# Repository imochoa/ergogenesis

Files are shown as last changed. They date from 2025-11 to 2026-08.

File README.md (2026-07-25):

https://www.youtube.com/watch?v=X0gTMRLRNp0

# Refs
- https://docs.ergogen.xyz/
- [measure your hand](https://pashutk.com/ergopad/)
    - https://github.com/pashutk/ergopad

- flatfootfox but for my usecase:   I'd take a look at the Sweep-like example on https://ergogen.ceoloide.com/ (via the dropdown). It does the sort of direct-pin + GND setup you're looking for;

- Check out my Corney Island (https://github.com/ceoloide/corney-island), it's a 100% replica of the Corne but has support for other switches (I use Lofree switches and I am loving it)

# Similar boards
https://github.com/auryn31/avocado
https://github.com/Narkoleptika/josukey

## [Part 1: Units](https://flatfootfox.com/ergogen-part1-units-points/)
Play around on https://ergogen.ceoloide.com/

## [Part 2: Outlines](https://flatfootfox.com/ergogen-part2-outlines/)
- https://github.com/scipioni/clavis

## [Part 3: PCB](https://flatfootfox.com/ergogen-part3-pcbs/)

## [Part 4: ](https://flatfootfox.com/ergogen-part4-footprints-cases/)

https://github.com/freerouting/freerouting

# ferris reversible examples
https://github.com/davidphilipbarr/Sweep/tree/main/Sweep%20half-swept

# Routing
1. Generate `outputs/pcbs/*.kicad_pcb
2. start kicad (`pcbnew`)
    1. import `.kicad_pcb`
    2. save it to let KiCAD auto-convert the file to the newer kicad sytanx
3. `File > Export > Specctra DSN` to generate a `.dsn` file
    - save at `ergogenesis/hardware/ergogen/output/pcbs/shield-pcb.dsn`
4. Start [freerouting](https://github.com/freerouting/freerouting)
    1. run it
6. save output as a Specctra SESSION in GUI `-routed.ses`
7. from kicad, with `.kicad_pcb` from before still open...
    1. `File > Import > Specctra Session`

# 3D models

Component STEP models live in `hardware/ergogen/3dmodels/` and are wired into the
footprints in `hardware/ergogen/config.yaml` via each footprint's `*_3dmodel_filename`
params. The generated `output/pcbs/shield-pcb.kicad_pcb` references them with
the `${ERGOGEN_3DMODELS}` KiCad path variable.

Models (downloaded from github.com/Andreyod1/Axiom, the ScottoKeebs library):
- `choc_v1.step` — Kailh Choc V1 switch (PG1353)
- `choc_hotswap.step` — Choc hotswap socket
- `choc_keycap_1u.step` — MBK 1u keycap
- `supermini_nrf52840.step` — Nice!Nano V2 STEP as a SuperMini NRF52840
  stand-in (same Pro Micro form factor / USB-C; no public SuperMini STEP
  exists)
- `switch_msk12c02.step` — MSK12C02 / SSSS811101 side slide switch
- `jst_ph_s2b.step` — JST PH 2.0 side-entry battery connector (S2B-PH-K,
  from the KiCad standard library)

To make KiCad's 3D viewer resolve them, add the path variable once:
- KiCad -> Preferences -> Configure Paths... -> Add
  - Name:  `ERGOGEN_3DMODELS`
  - Value:  `<repo>/hardware/ergogen/3dmodels`

Then open `hardware/ergogen/output/pcbs/shield-pcb.kicad_pcb` -> View -> 3D Viewer.

# Cases & plates

The `cases:` section generates a sandwich case: the PCB sits between a
**stabilization (switch) plate** on top and a **base plate** on the bottom,
held together by M2 screws through the mounting holes.

- `switch_plate` / `switch_plate_ol.dxf` — top plate with Choc cutouts
  (13.8x13.8mm) at each key. The switch snaps into this plate so it can't
  fall out of the hotswap socket. 1.6mm thick (Choc clip engagement).
- `bottom_plate` / `bottom_plate_ol.dxf` — base plate with a clearance slot
  per key for the hotswap socket.

The DXFs (`output/outlines/`) are for laser/waterjet cutting the plates; the
`.jscad` cases (`output/cases/`) are 3D-printable extrusions. Convert jscad to
STL with:
```
just ergogen-stl-from-jscad
# or per file:
npx @jscad/cli@1 output/cases/switch_plate.jscad -of stla -o switch_plate.stl
```
Preview a plate outline:
```
just visualize-dxf ./output/outlines/switch_plate_ol.dxf
```

## Hotswap socket clearance (reversible board)

The Choc hotswap socket bridges the switch's central hole and a side hole on
the north side of each key. On this reversible footprint the socket sits
bottom-west when populated on the front and bottom-east when populated on the
back. Rather than generate two mirrored bases, the base uses one symmetric
12x5mm slot per key that covers **both** positions, so a single base works
for either side (and for both halves of a split where one PCB is flipped).

The slot size/position is controlled by `socket_cutout_w`, `socket_cutout_h`,
and `socket_cutout_y` in the `units:` section. If a socket fouls the base,
widening `socket_cutout_w` or raising `socket_cutout_y` gives more room.

## Notes / known gotchas

- The top-left mounting screw (`mountscrew_top_left`) sits ~2mm from the
  `pinky_top` key, so in the switch plate its hole merges into that key's
  Choc cutout. Move that screw (or the key) if you need a clean separate
  screw hole in the top plate. The base plate is unaffected.
- The case here is a bare sandwich (no walls). Walls can be added later by
  extruding an expanded outline and subtracting the board outline, à la the
  flatfootfox Part 4 case tutorial.

# ZMK
```
warning: Deprecated symbol NRF_STORE_REBOOT_TYPE_GPREGRET is enabled.
```

# Save container history

```
   0 drwxr-xr-x. 1 root   root    20 Jun  5  2024 ../
4.0K -rw-------. 1 ubuntu ubuntu 437 Nov 17 16:43 .bash_history
4.0K -rw-r--r--. 1 ubuntu ubuntu 220 Mar 31  2024 .bash_logout
4.0K -rw-r--r--. 1 root   root   475 Oct  4 14:44 .bashrc
   0 drwxr-xr-x. 5 ubuntu ubuntu  51 Nov 17 16:39 .cache/
   0 drwxr-xr-x. 3 ubuntu ubuntu  22 Nov 17 16:39 .cmake/
   0 drwxr-xr-x. 3 ubuntu ubuntu  20 Nov 17 16:30 .dotnet/
4.0K -rw-r--r--. 1 ubuntu ubuntu 760 Nov 17 16:39 .gitconfig
   0 drwx------. 2 ubuntu ubuntu  80 Nov 17 16:30 .gnupg/
   0 drwxr-xr-x. 1 root   root    17 Nov 17 15:32 .local/
4.0K -rw-r--r--. 1 ubuntu ubuntu 807 Mar 31  2024 .profile
   0 drwxr-xr-x. 2 ubuntu ubuntu  25 Nov 17 16:30 .ssh/
   0 drwxr-xr-x. 1 ubuntu ubuntu  70 Nov 17 16:30 .vscode-server/
   0 drwxr-xr-x. 1 ubuntu ubuntu   6 Nov 17 15:32 project/
```

# Reference

- https://github.com/ceoloide/corney-island
  - build in docker? https://github.com/ceoloide/corney-island/blob/main/build.sh
https://github.com/ceoloide/ergogen-footprints/tree/main

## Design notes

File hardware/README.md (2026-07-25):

# Learnings
## V1.0
- Only need to hw swap the pins that cannot be mapped via software

## V2.0
- the hotswap socket pads are long and connected to the plated holes! This makes heating them up for soldering quite hard

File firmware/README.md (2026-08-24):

 The new global-quick-tap-ms = <75>; settings makes it so that if any key was pressed within 75ms before the combo hit, the combo won't be run and instead the keys will register as taps.

This significantly reduces accidental activations during typing and made combos finally usable for me.

## Battery sensing and Pro Micro pin 21

Do not configure the SuperMini battery sensor on AIN7 / P0.31. The `nice_nano`
board maps that GPIO to Pro Micro pin 21, and this keyboard already uses pin 21
as a direct key input:

- left half: `middle_home` (`D` on the base layer)
- right half: `inner_top` (`Y` on the base layer)

A `zmk,battery-voltage-divider` node using `io-channels = <&adc 7>` takes over
P0.31 and stops both keys from scanning. Battery ADC sensing and split battery
proxying therefore stay disabled in `config/ergogenesis.conf` and
`config/boards/shields/ergogenesis/Kconfig.defconfig`. Re-route those keys or
use a different battery-sense GPIO before enabling battery measurement.

## Keymap Drawing

https://github.com/infused-kim/zmk-config/blob/chocofi/main/keymap_img/keymap_img_adjuster.py

```
echo 'Parsing ZMK keymap...'
keymap -c keymap_config.yaml parse -c 12 -z ../config/corne.keymap > keymap.yaml

# echo '\n\nAdjusting keymap yaml...'
# ./keymap_img_adjuster.py keymap.yaml

echo '\n\nDrawing keymap...'
keymap -c keymap_config.yaml draw --qmk-keyboard crkbd/rev1 --qmk-layout LAYOUT_split_3x6_3 keymap.yaml -s Base Nav Num Func Sym Adjust > keymap.svg
```

## External modules (urob)

Two [urob](https://github.com/urob) ZMK modules are pinned in
[`config/west.yml`](config/west.yml). Both track ZMK `main` (their `main`
branch) — the `v0.3` in their READMEs is a "match your ZMK release" convention,
not a floor — so they build against this repo's ZMK-main pin. Bump the SHAs in
`west.yml` to move forward, then re-run `just firmware west-update` + a pristine
build.

- **[zmk-unicode](https://github.com/urob/zmk-unicode)** — Unicode input via the
  `&uc` behavior. Type code points directly (`&uc 0xE4 0xC4` → `ä`/`Ä`) or with
  language macros (`&uc UC_DE_AE`). Supports six input systems (macOS, Linux,
  Linux-alt, WinCompose, Windows-Alt, Emacs) with **runtime switching** — the
  keymap sets a boot default via `UC_DEFAULT` / `default-mode` and the
  `&uc UC_SET_MACOS` / `&uc UC_SET_LINUX` keys on the `LY_CTL` layer flip it
  live (no host-OS auto-detection exists in ZMK; this is the switch). macOS
  needs the "Unicode Hex Input" keyboard enabled.

- **[zmk-helpers](https://github.com/urob/zmk-helpers)** — convenience macros for
  terser keymaps: `ZMK_COMBO`, `ZMK_MACRO`, `ZMK_HOLD_TAP`, `ZMK_MOD_MORPH`,
  `ZMK_LAYER`, and standardized key-position labels (`LT0`…`RH2`, `KEYS_L`,
  `KEYS_R`, `THUMBS`). Included via `#include "zmk-helpers/helper.h"`. The custom
  shield keeps a local snapshot of the module's standard `36.h` position labels
  so it remains self-contained. The module's `unicode-chars/*.dtsi` are
  deprecated in favor of the zmk-unicode module above.

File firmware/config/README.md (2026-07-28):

Overrides the sources at config/boards/shields/ergogenesis/ergogenesis.keymap

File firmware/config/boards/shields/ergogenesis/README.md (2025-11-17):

https://github.com/zmkfirmware/zmk/blob/main/app/boards/shields/cradio/README.md

# [https://zmk.dev/docs/development/hardware-integration/new-shield?keyboard-type=split#kscan](Kscan)

> **ZMK uses the blue color coded "Arduino" pin names to generate devicetree node references.**
For example, to refer to the pin labeled 0 in the diagram, use &pro_micro 0 in the devicetree files.

# Mapping pin numbers...
https://github.com/zmkfirmware/zmk/blob/4ec69cb7e658590adf6354027aca789b364a70c5/app/boards/arm/nrfmicro/arduino_pro_micro_pins.dtsi

`.dtsi` names are NOT the pin numbers!

https://github.com/zmkfirmware/zmk/blob/main/app/boards/shields/cradio/cradio.dtsi

https://github.com/zmkfirmware/zmk/tree/4ec69cb7e658590adf6354027aca789b364a70c5/app/boards/arm/nice_nano

https://github.com/zmkfirmware/zmk/blob/4ec69cb7e658590adf6354027aca789b364a70c5/app/boards/arm/nice_nano/arduino_pro_micro_pins.dtsi

PIN#? | ???? | D
-- | -- | --
0  | 8  | D0
1  | 6  | D1
2  | 17 | D2
3  | 20 | D3
4  | 22 | D4/A6
5  | 24 | D5
6  | 0  | D6/A7
7  | 11 | D7
8  | 4  | D8/A8
9  | 6  | D9/A9
10 | 9  | D10/A10
16 | 10 | D16
14 | 11 | D14
15 | 13 | D15
18 | 15 | D18/A0
19 | 2  | D19/A1
20 | 29 | D20/A2
21 | 31 | D21/A3

## Changing the pin numbers
https://github.com/zmkfirmware/zmk/tree/main/app/boards/shields/cradio#pin-arrangement

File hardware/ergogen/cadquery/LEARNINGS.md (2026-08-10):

# CadQuery path — learnings and notes

This document records what we learned while adding a CadQuery-based pipeline to
generate STEP/STL for the plates and full case directly from Ergogen DXFs, and
then verifying geometry parity against the existing JSCAD meshes.

## Why CadQuery

- FreeCAD CLI is capable but finicky for headless scripting (argument passing,
  module pathing, exporter behavior). We had trouble invoking our scripts
  reliably via `freecadcmd -c` and getting writes to land.
- CadQuery exposes a clean Python API on top of OCP/OpenCascade and runs as a
  normal Python process. With uv single-file scripts we get reproducible,
  dependency-isolated CLIs that are easy to call from `just`.

## Source geometry (DXFs)

All solids are built exclusively from outlines exported by Ergogen:

- switch_plate_ol.dxf — PCB outline minus Choc cutouts and screw holes
- bottom_plate_ol.dxf — PCB outline minus socket slots and screw holes
- case_base_ol.dxf — solid base (board outline minus screw holes)
- wall_ring_ol.dxf — outer perimeter ring (expanded outline minus board outline)
- standoff_ol.dxf — circles at screw positions (standoffs)
- holes_ol.dxf — screw through-holes
- switch_wall_cutout_ol.dxf — rectangle through the case wall for power switch
- usb_wall_cutout_ol.dxf — rectangle through the north wall for USB-C

Note: a few of these outlines were added to `config.yaml` specifically to make a
reliable case reconstruction possible in external CAD.

## Scripts (uv single-file CLIs)

- cadquery/extrude_dxf.py
  - Input: one DXF outline
  - Builds faces from closed wires, extrudes to a prism; if multiple wires are
    present, it treats the largest as the outer boundary and the rest as holes.
  - Output: STEP (+ optional STL)
  - Usage example:
    - uv run cadquery/extrude_dxf.py \
      --dxf ergogen/output/outlines/switch_plate_ol.dxf \
      --height 1.6 \
      --out-step ergogen/output/cases/switch_plate_cq.step \
      --out-stl ergogen/output/cases/switch_plate_cq.stl

- cadquery/build_case.py
  - Inputs: the DXF set listed above (via a directory), plus bottom/standoff
    heights and wall height.
  - Build recipe (all via boolean ops):
    - base = case_base_ol.extrude(bottom_th)
    - walls = wall_ring_ol.extrude(bottom_th + standoff_h + wall_h)
    - standoffs = standoff_ol.extrude(bottom_th + standoff_h)
    - case = base ∪ walls ∪ standoffs
    - holes = holes_ol.extrude(full_height) → case = case − holes
    - switch_cut, usb_cut extruded to full height → subtract from case
  - Output: STEP (+ optional STL)
  - Usage example:
    - uv run cadquery/build_case.py \
      --dxf-dir ergogen/output/outlines \
      --bottom-th 2.0 --standoff-h 2.0 --wall-h 5.0 \
      --out-step ergogen/output/cases/case_cq.step \
      --out-stl ergogen/output/cases/case_cq.stl

## Just recipes

- just hardware cq-build-plates — build switch/bottom plates (STEP+STL)
- just hardware cq-build-case — build the case (STEP+STL)
- just hardware cq-compare — compare CadQuery vs JSCAD meshes
- just hardware cq-iterate — one-shot build-everything-then-compare

These search heights from `ergogen/config.yaml` with ripgrep and write to
`ergogen/output/cases/`.

## Comparison methodology

- Tool: `ergogen/freecad/compare_meshes.py` (uv script using trimesh + scipy + rtree)
- Metrics:
  - Volume difference (absolute and relative %)
  - Surface area difference (absolute)
  - Approximate bidirectional Hausdorff distance (sampling-based)
- Defaults: ≤0.1% volume difference and ≤0.05 mm Hausdorff distance qualify as
  a match. You can pass different tolerances on the CLI if needed.

## Results (with current config)

- Switch plate: ΔV ~0.0033%, Hausdorff ~0.0071 mm (MATCH)
- Bottom plate: ΔV ~0.0024%, Hausdorff ~0.0075 mm (MATCH)
- Case (base+walls+standoffs−holes−cutouts): ΔV ~0.0025%, Hausdorff ~0.0142 mm (MATCH)

These are well within manufacturing tolerances and typical mesh discretization
error.

## API gotchas and fixes

- CadQuery DXF import returns a Workplane, not a Compound. Use:
  - `wp = importers.importDXF(path)`
  - `wires = [w for w in wp.wires().vals() if isinstance(w, cq.Wire) and w.Closed()]`
- Building solids from faces:
  - `cq.Face.makeFromWires(outer, holes)` creates a planar face with holes.
  - Faces don’t have `.extrude()`, so wrap in a Workplane: `cq.Workplane("XY").add(face).extrude(h)`
- Full case needs proper “holes in faces” handling (outer wire + hole wires).
  A naïve “extrude all wires, then subtract” can fail on shared boundaries.
- Export tolerances: CadQuery’s default tessellation was sufficient to match the
  JSCAD meshes within ~0.01 mm; if a future model needs tighter control, we can
  expose tessellation parameters explicitly.

## FreeCAD notes (why we pivoted)

- Argument passing through `freecadcmd` is inconsistent across versions. `--`
  and `--pass` behave differently; reading args and writing files was unreliable
  in our environment.
- Module import path for neighbor modules required extra `sys.path` tweaks.
- We left the FreeCAD scripts in place for reference, but the CadQuery path is
  now the recommended one.

## Dependencies

- uv is used to run the single-file scripts. Install once from Astral if
  missing.
- CadQuery pulls OCP/VTK/Numba/etc.; first run will download a few hundred MB.
- The compare tool depends on trimesh, numpy, scipy, and rtree.

## Future work

- Parameterize STL tessellation for CQ exports if we ever need 1:1 triangle
  parity (currently unnecessary).
- Wrap the CadQuery builds into a single orchestrator script (optional), though
  `just cq-iterate` already provides a good UX.

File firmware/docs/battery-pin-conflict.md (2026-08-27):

# Battery sensing and the Pro Micro pin 21 conflict

## Summary

Battery voltage sensing is intentionally disabled on Ergogenesis. The SuperMini
nRF52840's battery voltage divider uses `AIN7`, which is the nRF52840 pin
`P0.31`. ZMK's `nice_nano` board definition also maps Pro Micro pin 21 to
`P0.31`, and Ergogenesis uses pin 21 as a direct key input on both halves.

Enabling a `zmk,battery-voltage-divider` sensor on ADC channel 7 therefore stops
these keys from scanning:

- left half: `middle_home` (`D` on the base layer)
- right half: `inner_top` (`Y` on the base layer)

Battery sensing can only be enabled safely after rerouting those keys or using a
battery-sense circuit connected to a different ADC-capable pin.

## Power and pin terminology

### VDD and VDDH

`VDD` is the normal low-voltage supply for the nRF52840's logic, usually around
3.3 V. `VDDH` is the chip's high-voltage supply input. It accepts approximately
2.5-5.5 V, allowing a LiPo battery, which reaches about 4.2 V when fully
charged, to power it directly. The names come from traditional MOS circuit
notation; the `H` denotes the high-voltage supply.

A genuine nice!nano v2 uses the nRF52840's high-voltage mode approximately as
follows:

```text
LiPo battery
    |
    v
  VDDH ---- internal VDDH/5 measurement ---> ADC
    |
 internal regulator
    |
    v
   VDD ----> nRF52840 logic and low-voltage rail
```

The nRF52840 can measure an internally divided version of VDDH without using an
external GPIO. ZMK therefore describes the nice!nano v2 sensor as:

```dts
compatible = "zmk,battery-nrf-vddh";
```

This measurement method does not conflict with Pro Micro pin 21.

The SuperMini design assumed by this project uses a different power and sensing
arrangement:

```text
LiPo ---> RAW ---> board regulator ---> VDD / 3.3 V
  |
  `---- resistor divider ---> P0.31 / AIN7
```

Measuring VDD would not provide a useful battery level because the regulator
holds it near 3.3 V for most of the discharge cycle. The SuperMini instead
exposes a divided version of the original battery voltage to an ADC-capable
GPIO. SuperMini clones vary, so this circuit and its resistor values must be
confirmed against the actual controller rather than inferred from the
nice!nano-compatible footprint.

### P0.31, D21, A3, and AIN7

The nRF52840 groups its GPIOs into numbered ports:

- port 0 contains `P0.00` through `P0.31`;
- port 1 contains `P1.00` through `P1.15`.

`P0.31` therefore means pin 31 within GPIO port 0. It is not package pin 31 or
Pro Micro pin 31. Devicetree normally represents it as `&gpio0 31`.

A physical SoC pin can have several functions and several names at different
abstraction levels. For this pin, the complete mapping is:

```text
Pro Micro D21 / A3 ---> nRF52840 P0.31 ---> digital GPIO
                                         `-> SAADC input AIN7
```

| Name | Meaning |
|---|---|
| `D21` or Pro Micro pin 21 | Logical connector/header pin |
| `A3` | Pro Micro analog-style connector label |
| `P0.31` | nRF52840 GPIO port 0, pin 31 |
| `AIN7` | nRF52840 SAADC function on `P0.31` |
| `&gpio0 31` | Devicetree representation of `P0.31` |
| `&adc 7` | Devicetree selection of `AIN7` |

The ZMK board mapping makes the connector-to-SoC relationship explicit:

```dts
<21 0 &gpio0 31 0> /* D21/A3 */
```

Consequently, these two declarations request different functions of the same
physical pin:

```dts
input-gpios = <&pro_micro 21 (GPIO_ACTIVE_LOW | GPIO_PULL_UP)>;
io-channels = <&adc 7>;
```

The first uses `P0.31` as a digital key input; the second uses it as analog input
`AIN7` for battery measurement.

## History

The relevant commits are:

```text
8a66947  trying to measure battery level
a6fb741  fixed battery conflicts
```

Commit `8a66947` added a battery node similar to:

```dts
/ {
    chosen {
        zmk,battery = &vbatt;
    };

    vbatt: vbatt {
        compatible = "zmk,battery-voltage-divider";
        io-channels = <&adc 7>;
        output-ohms = <1000000>;
        full-ohms = <2000000>;
    };
};
```

This made battery measurement available, but ADC channel 7 took over the same
physical pin used by the key scanner. Commit `a6fb741` removed the sensor and
split battery forwarding after the `D` and `Y` failures were identified.

Before that change, the build targeted the base `nice_nano` board without a
revision overlay that supplied a suitable `zmk,battery` node. ZMK could still
expose battery reporting while having no real battery sensor, resulting in a
level that remained around its default value. A visible battery service or
`CONFIG_ZMK_BATTERY_REPORTING=y` does not by itself prove that voltage is being
measured.

## Where the conflict is recorded

The repository contains warnings at the points most likely to be edited:

- `README.md` — user-facing explanation
- `config/ergogenesis.conf` — battery sensing and split forwarding are disabled
- `config/boards/shields/ergogenesis/ergogenesis.dtsi` — warning beside the
  left-half pin 21 key input
- `config/boards/shields/ergogenesis/ergogenesis_right.overlay` — warning beside
  the right-half pin 21 key input

The underlying board mapping is in the west-managed ZMK source:

```text
zmk/app/module/boards/nicekeyboards/nice_nano/arduino_pro_micro_pins.dtsi
```

It contains:

```dts
<21 0 &gpio0 31 0> /* D21/A3 */
```

The full resource chain is therefore:

```text
battery voltage divider -> SAADC AIN7 -> nRF52840 P0.31
Pro Micro pin 21        -> GPIO0 pin 31 -> nRF52840 P0.31
kscan key input         -> Pro Micro pin 21
```

`A3` is the connector's analog-style label; `AIN7` is the nRF52840 SAADC input
connected to the same physical SoC pin.

## Why the build did not catch it

Devicetree validation does not generally detect this conflict. The key scanner
references a GPIO through the Pro Micro connector mapping, while the battery
sensor references an ADC channel:

```dts
input-gpios = <&pro_micro 21 (GPIO_ACTIVE_LOW | GPIO_PULL_UP)>;
io-channels = <&adc 7>;
```

Both declarations are valid independently. The relationship between SAADC
channel 7 and `P0.31` is fixed by the nRF52840 hardware and is not represented as
a shared devicetree resource with exclusive ownership. Consequently, `dtc` can
compile both uses without warning even though they conflict at runtime.

The generated devicetree provides the evidence, but identifying the conflict
requires resolving connector aliases and peripheral channels down to physical
SoC pins.

## Resource-audit procedure for future changes

Use this procedure before adding any ADC, SPI, I2C, UART, PWM, LED, display, or
other pin-using feature.

### 1. Identify the actual hardware resource

Consult the controller schematic or trusted pinout and the nRF52840 product
specification. Do not assume that a SuperMini clone has the same battery circuit
as a nice!nano revision merely because it uses the same ZMK board target.

Record:

- the physical SoC GPIO, such as `P0.31`
- alternate peripheral functions, such as `AIN7`
- onboard circuitry already attached to the pin
- whether the function is present on every controller variant in use

### 2. Resolve connector pin aliases

For every `&pro_micro N` reference, inspect the active board's `gpio-map` and
translate it to `gpio0` or `gpio1`. For example:

```text
&pro_micro 21 -> &gpio0 31 -> P0.31
```

Do this for both halves. Ergogenesis is reversible and reverse-mounts the MCU,
so the same controller pin can correspond to different physical keys on the two
halves.

### 3. Compare all consumers

Search the shield, board, and generated configuration:

```bash
rg -n 'input-gpios|io-channels|gpios|pwms|pinctrl|zmk,battery' \
  config/boards zmk/app/module/boards/nicekeyboards/nice_nano
```

Build a small resource table when a change uses more than one pin:

| SoC resource | Connector pin | Existing consumer | Proposed consumer |
|---|---:|---|---|
| `P0.31 / AIN7` | Pro Micro 21 | direct key input | battery ADC |

A physical resource should not have two active consumers unless the hardware and
drivers explicitly support sharing it.

### 4. Inspect the resolved build outputs

Build both halves and generate the reports:

```bash
# From firmware/
just build-all
just devicetree-report-all
just kconfig-report-all

# Or from the repository root
just firmware build-all
just firmware devicetree-report-all
just firmware kconfig-report-all
```

Inspect each target, not only the central half:

```text
.build/nice_nano/ergogenesis_left/zephyr/zephyr.dts
.build/nice_nano/ergogenesis_left/zephyr/.config
.build/nice_nano/ergogenesis_left/zephyr/devicetree-report.html
.build/nice_nano/ergogenesis_left/zephyr/kconfig-report.html

.build/nice_nano/ergogenesis_right/zephyr/zephyr.dts
.build/nice_nano/ergogenesis_right/zephyr/.config
.build/nice_nano/ergogenesis_right/zephyr/devicetree-report.html
.build/nice_nano/ergogenesis_right/zephyr/kconfig-report.html
```

Verify all of the following:

- `chosen.zmk,battery` points to the intended sensor.
- The intended sensor node exists and has `status = "okay"` where applicable.
- `io-channels` uses the expected ADC channel.
- The resolved `gpio-map` agrees with the controller pinout.
- Neither half's `kscan0.input-gpios` resolves to the same physical pin.
- Kconfig enables the actual battery sensor, not only battery reporting or split
  proxying.

The CI recipe also publishes `zephyr.dts`, the combined `.config`, and both HTML
reports under each target's `debug/` artifact directory.

### 5. Perform a hardware smoke test

A successful build is not sufficient for pin multiplexing changes. Before
relying on battery readings:

1. Test every key on both halves.
2. Confirm that battery voltage changes over time rather than remaining at a
   default value.
3. Compare the reported voltage or percentage with a multimeter.
4. Test USB-powered and battery-powered operation.
5. Verify central and peripheral battery reporting separately before enabling
   split fetching or proxying.

## Safe ways to restore battery measurement

Possible hardware solutions are:

1. Reroute both keys currently connected to Pro Micro pin 21 to unused GPIOs.
2. Use a controller whose battery sensor does not consume a key-scanning pin.
3. Add a battery divider on another suitable ADC-capable GPIO and describe its
   actual resistor values in devicetree.

Do not simply re-enable `io-channels = <&adc 7>` or the split battery Kconfig
options. Split fetching and proxying only transport readings; they cannot fix a
missing or conflicting physical sensor.

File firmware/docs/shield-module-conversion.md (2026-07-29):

# TODO (future): convert the ergogenesis shield to a ZMK module

**Status:** not started — deferred on purpose. The build works today; this is
future-proofing / cleanup only. Do NOT do this reactively.

## Context

`just build-all` currently prints:

```
CMake Deprecation Warning at keymap-module/modules/modules.cmake:53 (message):
  The `config/boards` folder is deprecated. Please use a module instead.
```

It fires from `zmk/app/keymap-module/modules/modules.cmake:53`, guarded by
`if(EXISTS ${ZMK_CONFIG}/boards)`. So the warning is triggered purely by the
existence of `config/boards/` — nothing more. It is a **warning, not an error**;
all three `.uf2` targets build fine with it. ZMK is steering everyone off the
in-config `config/boards/` layout toward shipping a shield as a standalone
**Zephyr/ZMK module**.

**Why bother later:** (a) silences the warning; (b) if ZMK ever promotes it to
an error, the build breaks; (c) a module is a reusable, publishable unit if we
ever want to share the shield. **Why not now:** it touches the same
board-discovery / `west` machinery documented as hard-won in `AGENTS.md`, needs
a `west-update` + pristine rebuild to validate, and buys zero functional change.

## Current layout (relevant bits)

```
firmware/
├── config/                         # west manifest root (self.path: config), ZMK_CONFIG
│   ├── west.yml
│   ├── ergogenesis.conf
│   ├── settings_reset.conf
│   ├── ergogenesis.keymap          # keymap OVERRIDE (edited here); includes
│   │                               #   boards/shields/ergogenesis/{36,helper}.h (relative to config/)
│   └── boards/shields/ergogenesis/ # <-- THIS dir triggers the deprecation
│       ├── ergogenesis.zmk.yml  ergogenesis.dtsi  ergogenesis.keymap (fallback)
│       ├── ergogenesis_left.overlay  ergogenesis_right.overlay
│       ├── 36.h  helper.h  ergogenesis.conf
│       └── Kconfig.shield  Kconfig.defconfig
└── .just/in-devc.just              # generic-build: `west build zmk/app -- -DZMK_CONFIG=config -DSHIELD=...`
```

Build invocation (`.just/in-devc.just`, `generic-build`):
`west build … zmk/app -- -DZMK_CONFIG=/workspace/config -DSHIELD=ergogenesis_left …`

## Key fact that makes this cheap

ZMK reads a `ZMK_EXTRA_MODULES` CMake var and appends it to
`ZEPHYR_EXTRA_MODULES` — see `zmk/app/CMakeLists.txt:6`:

```cmake
set(ZEPHYR_EXTRA_MODULES "${ZMK_EXTRA_MODULES};${CMAKE_CURRENT_SOURCE_DIR}/module;…")
```

So an **in-tree** module (same repo, not a separate git remote) can be
registered with `-DZMK_EXTRA_MODULES=<abs path>` — no `west.yml` project entry
and no extra clone needed.

## Target layout

Move the shield out of `config/boards/` into a module dir (suggested name
`firmware/ergogenesis-module/`, flexible — just NOT `modules/`, which is
west-managed/gitignored):

```
firmware/
├── ergogenesis-module/
│   ├── zephyr/module.yml           # board_root: .
│   └── boards/shields/ergogenesis/ # moved verbatim from config/boards/shields/ergogenesis/
└── config/                         # keeps west.yml, *.conf, ergogenesis.keymap (override)
```

`ergogenesis-module/zephyr/module.yml`:

```yaml
build:
  settings:
    board_root: .
```

(Only `board_root` — the shield has no separate `dts/` bindings dir, so no
`dts_root` needed.)

## Steps

1. `mkdir -p firmware/ergogenesis-module/zephyr` and write `module.yml` (above).
2. `git mv config/boards/shields/ergogenesis firmware/ergogenesis-module/boards/shields/ergogenesis`
   (then remove the now-empty `config/boards/`). Use `git mv` to keep history.
3. In `.just/in-devc.just`, `generic-build`, add to the `west build … --` args:
   `-DZMK_EXTRA_MODULES="{{ fw }}/ergogenesis-module"`.
   `-DZMK_CONFIG=config` and `-DSHIELD=ergogenesis_{left,right}` stay as-is.
4. **Fix the override keymap's includes** (the main wrinkle — see below).
5. `just west-update` (registers nothing new but keeps state consistent), then
   `just build-all` **pristine** and confirm the deprecation warning is gone and
   all three `.uf2` still build.

## The one real wrinkle: keymap-override includes

`config/ergogenesis.keymap` currently does (resolved relative to `config/`):

```c
#include "boards/shields/ergogenesis/36.h"
#include "boards/shields/ergogenesis/helper.h"
```

Once `boards/` leaves `config/`, that path no longer resolves. Options, in order
of preference:

- **A (simplest, robust):** point at the module via a relative path from
  `config/`:
  ```c
  #include "../ergogenesis-module/boards/shields/ergogenesis/36.h"
  #include "../ergogenesis-module/boards/shields/ergogenesis/helper.h"
  ```
  Deterministic (quoted include resolves against the including file's dir); a bit
  ugly but zero build-system magic.
- **B (cleaner includes):** add the shield dir to the preprocessor include path
  (e.g. a `zephyr_include_directories()` in a shield `CMakeLists.txt`, or an
  `-I` in the build args) and switch to `#include <36.h>` / `<helper.h>`. Needs
  verifying that the shield `CMakeLists.txt` is picked up for a shield build.

The **fallback** shield keymap (`…/boards/shields/ergogenesis/ergogenesis.keymap`)
keeps its colocated `#include "./36.h"` — it sits next to the headers, so it is
unaffected by the move.

## Verification

- `just build-all` exits 0, produces `ergogenesis_left/right-nice_nano-zmk.uf2`
  + `settings_reset-nice_nano-zmk.uf2`.
- The `config/boards … deprecated` warning no longer appears in the log.
- Build log still shows `Using keymap file: …/config/ergogenesis.keymap` (the
  override is still in effect) — otherwise the keymap-include fix regressed.

## Rollback

All changes are file moves + a build-arg + include-path edits; `git revert` /
`git mv` back restores the working `config/boards` layout. No irreversible steps.

## Also note

`config/dts/` is deprecated by the same mechanism (`modules.cmake:56`) — we don't
use it, so nothing to do, but don't reintroduce it either.

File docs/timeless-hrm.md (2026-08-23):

# Timeless home-row mods alignment

Both keyboard configurations now follow the Timeless home-row-mod setup from
[urob/zmk-config](https://github.com/urob/zmk-config).

## Previous differences

Both configurations already used the core Timeless HRM mechanics:

- ZMK's `balanced` hold-tap flavor
- separate left- and right-hand HRM behaviors
- positional hold-taps
- `hold-trigger-on-release`

They differed from urob's configuration in these details:

| Setting | Previous | Aligned |
| --- | ---: | ---: |
| `tapping-term-ms` | 220 ms | 280 ms |
| `quick-tap-ms` | 150 ms | 175 ms |
| `require-prior-idle-ms` | 100 ms | 150 ms |

The positional trigger lists also included same-hand HRM positions:

```dts
hold-trigger-key-positions = <KEYS_R THUMBS KEYS_HRM_L>;
hold-trigger-key-positions = <KEYS_L THUMBS KEYS_HRM_R>;
```

They now match urob's opposite-hand-plus-thumbs configuration:

```dts
hold-trigger-key-positions = <KEYS_R THUMBS>;
hold-trigger-key-positions = <KEYS_L THUMBS>;
```

Ergogenesis's `THUMBS` definition previously omitted its two outer thumb keys.
It now includes all six thumb positions. The Ferris Sweep already included all
four of its thumb positions. Both position-label headers now provide urob's
standard `THUMBS_L`, `THUMBS_R`, and `THUMBS` definitions.

## Files changed

### Ergogenesis

- `ergogenesis/firmware/config/ergogenesis.keymap`
- `ergogenesis/firmware/config/boards/shields/ergogenesis/ergogenesis.keymap`
- `ergogenesis/firmware/config/boards/shields/ergogenesis/36.h`
- `ergogenesis/firmware/README.md`

### Ferris Sweep

- `ferris-sweep-zmk-nix/config/cradio.keymap`
- `ferris-sweep-zmk-nix/config/34.h`

## Validation

- A full left-side Ergogenesis Studio firmware build passed.
- Ferris Sweep CMake and devicetree generation passed against the same pinned
  ZMK version. The generated devicetree confirmed the 280/175/150 ms settings
  and the corrected positional trigger lists.
- A full standalone Ferris Sweep build was not completed because its fresh
  `west update` exceeded the validation timeout.
- `git diff --check` passed in both repositories.

## Unchanged generic hold-tap

The separate generic `&ht` behavior still uses 220/150/100 ms. It is not used by
the home-row mods, so it was intentionally left unchanged.

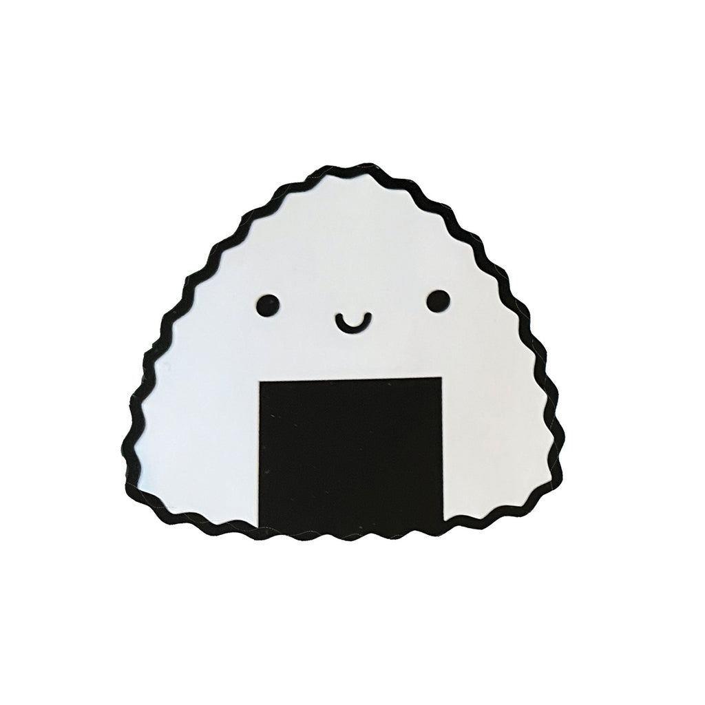
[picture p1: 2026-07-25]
hardware/pics/onigiristicker_1024x1024.jpg

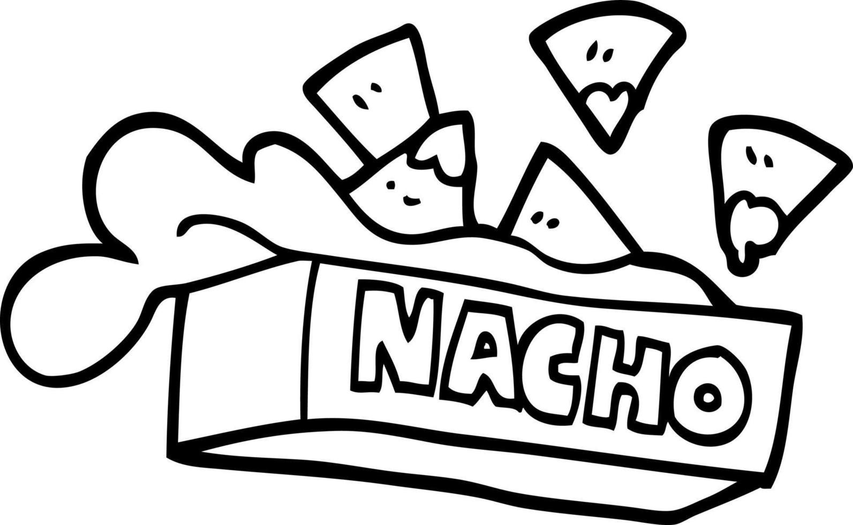
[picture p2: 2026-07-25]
hardware/pics/black-and-white-cartoon-nacho-box-vector.jpg

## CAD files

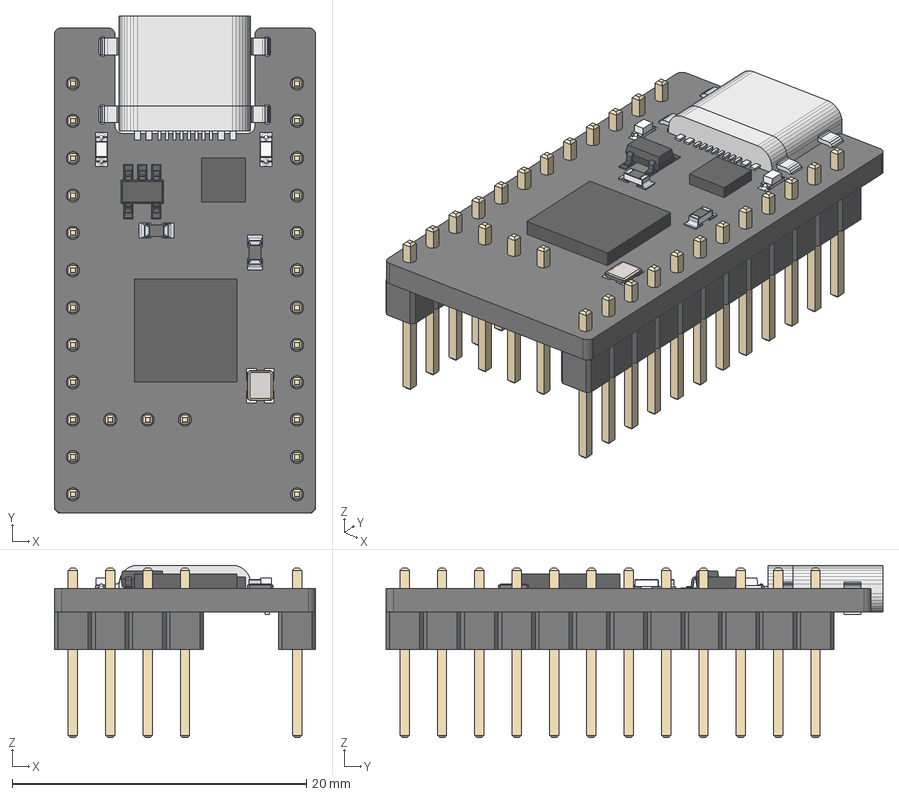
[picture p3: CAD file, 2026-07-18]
hardware/ergogen/3dmodels/supermini_nrf52840.step
17.8 x 33.8 x 11.7 mm
PinHeader_1x12_P2.54mm_Vertical.step
User Library-TYPE-C-31-M-14.step
MICRO_603 resistor 102
MICRO_stackable header pin x 12
MICRO_stackable header 12
micro_crystal 5x3
MICRO_led
micro_MIC5219

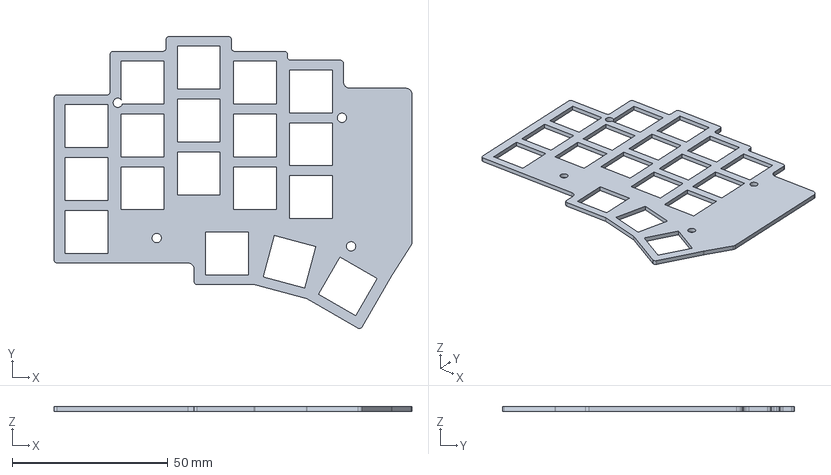
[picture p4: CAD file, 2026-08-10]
hardware/ergogen/output/cases/switch_plate_cq.step
115.0 x 93.8 x 1.60 mm

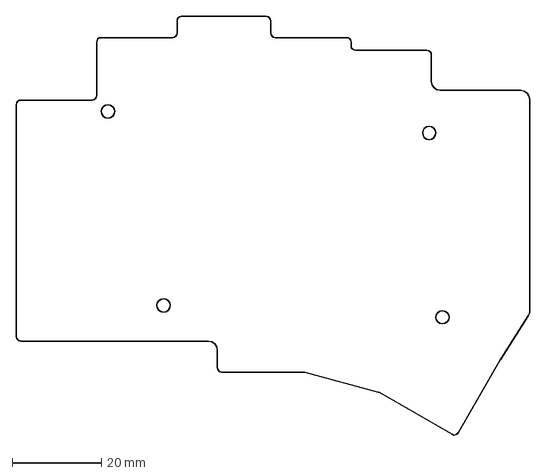
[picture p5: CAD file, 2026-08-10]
hardware/ergogen/output/outlines/case_base_ol.dxf
115.0 x 94.0 mm

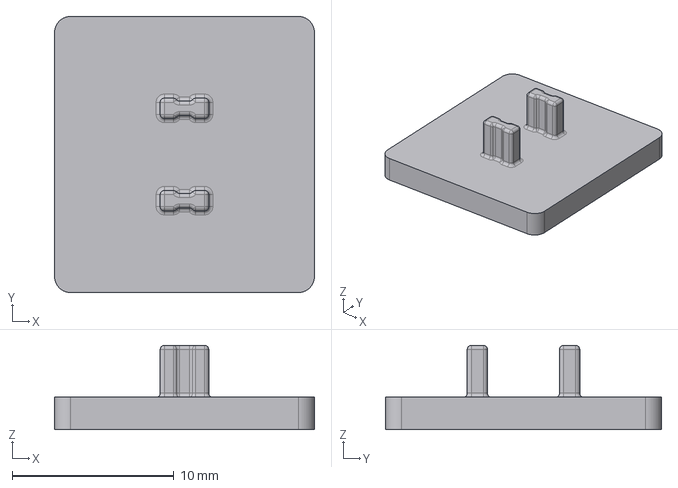
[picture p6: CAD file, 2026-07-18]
hardware/ergogen/3dmodels/choc_keycap_1u.step
16.1 x 17.0 x 5.20 mm

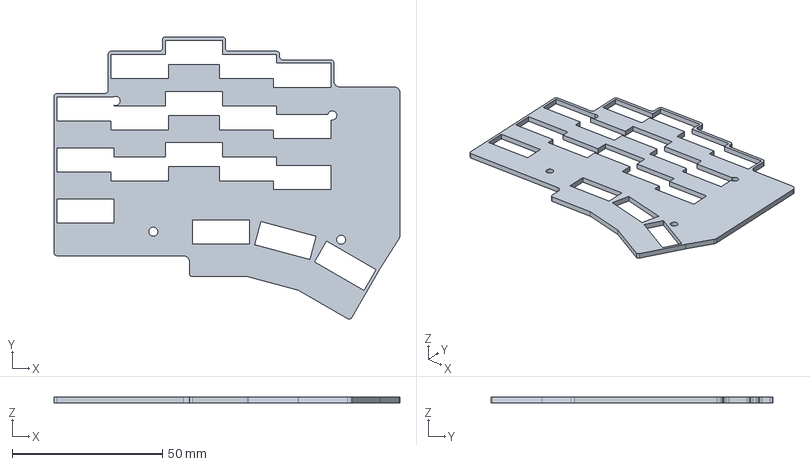
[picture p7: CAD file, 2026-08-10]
hardware/ergogen/output/cases/bottom_plate_cq.step
115.0 x 93.8 x 2.00 mm

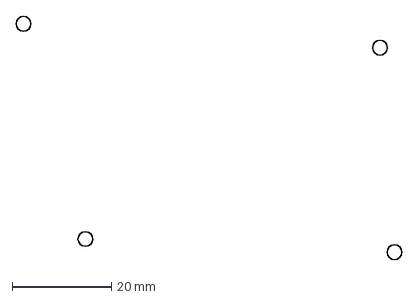
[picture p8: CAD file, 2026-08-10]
hardware/ergogen/output/outlines/holes_ol.dxf
77.9 x 49.1 mm

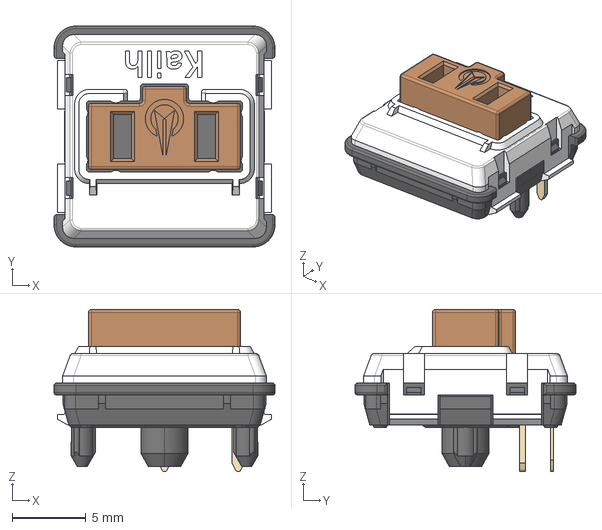
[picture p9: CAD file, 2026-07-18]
hardware/ergogen/3dmodels/choc_v1.step
15.0 x 15.0 x 11.0 mm

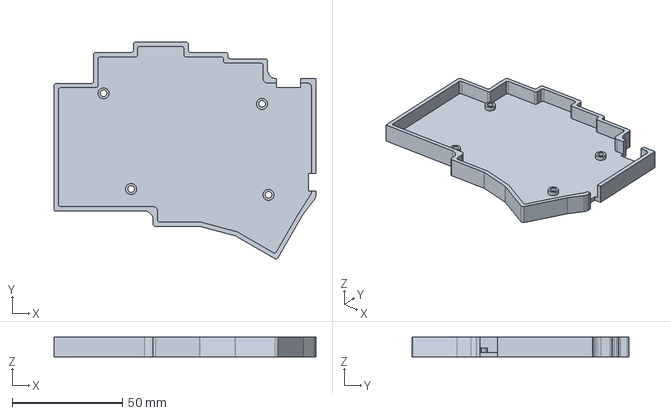
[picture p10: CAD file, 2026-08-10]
hardware/ergogen/output/cases/case_cq.step
119.0 x 98.6 x 9.00 mm

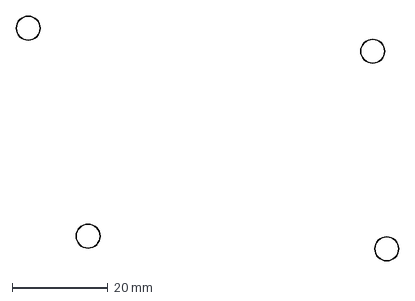
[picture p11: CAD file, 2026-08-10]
hardware/ergogen/output/outlines/standoff_ol.dxf
79.9 x 51.1 mm

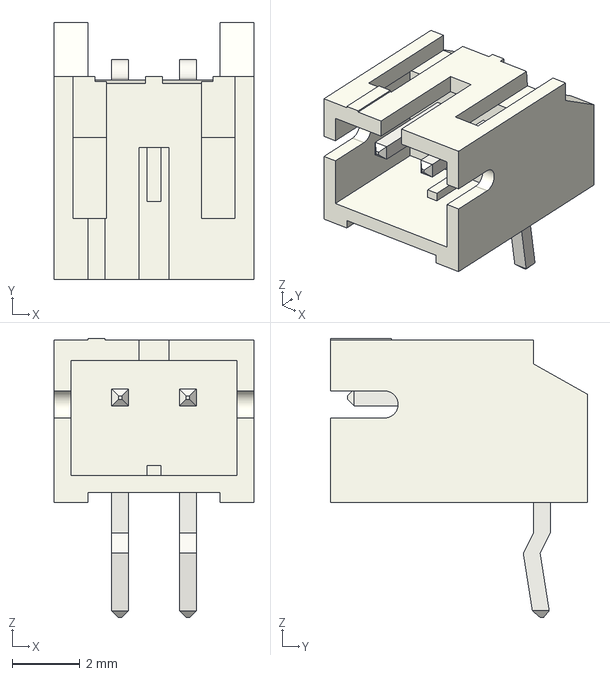
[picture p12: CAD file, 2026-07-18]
hardware/ergogen/3dmodels/jst_ph_s2b.step
5.90 x 7.60 x 8.25 mm

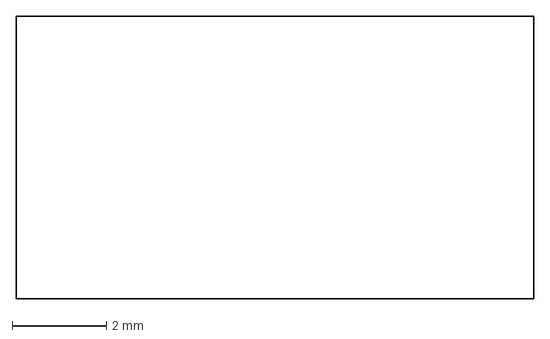
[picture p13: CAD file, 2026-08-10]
hardware/ergogen/output/outlines/usb_wall_cutout_ol.dxf
11.0 x 6.00 mm

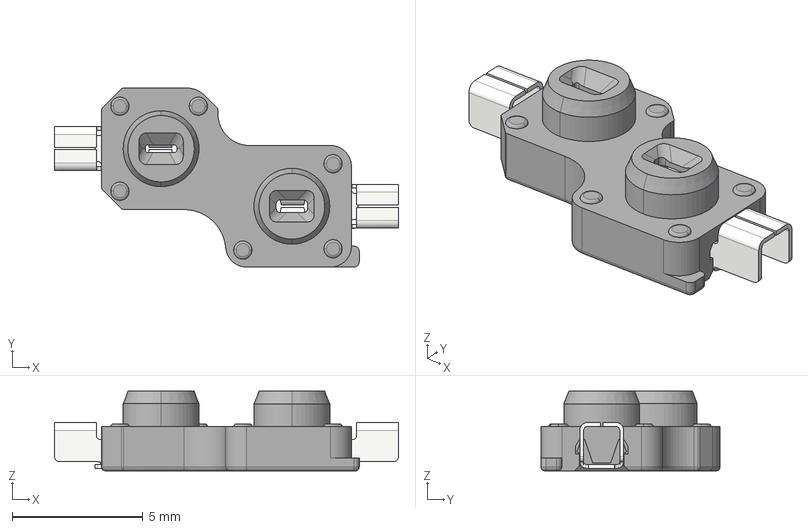
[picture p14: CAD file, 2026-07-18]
hardware/ergogen/3dmodels/choc_hotswap.step
13.2 x 6.85 x 3.05 mm

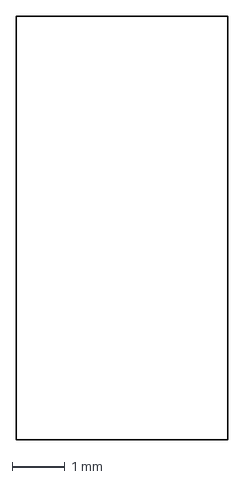
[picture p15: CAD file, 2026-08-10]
hardware/ergogen/output/outlines/switch_wall_cutout_ol.dxf
4.00 x 8.00 mm

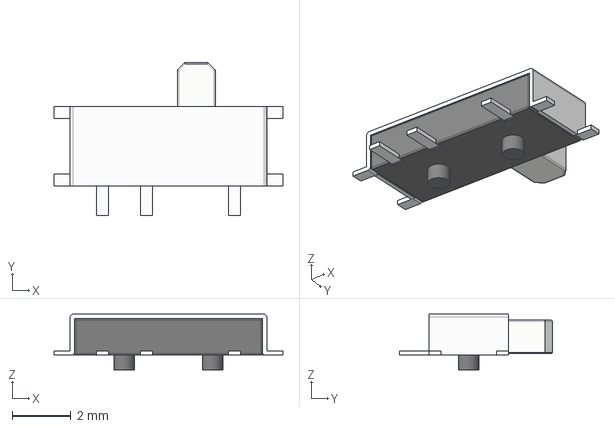
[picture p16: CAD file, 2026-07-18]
hardware/ergogen/3dmodels/switch_msk12c02.step
7.80 x 5.20 x 1.90 mm

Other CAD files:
hardware/ergogen/output/cases/case.stl
hardware/ergogen/output/cases/bottom_plate.stl
hardware/ergogen/output/cases/switch_plate.stl
hardware/ergogen/output/outlines/wall_ring_ol.dxf
ergogen/output/outlines/board_ol.dxf
ergogen/output/outlines/bottom_plate_ol.dxf
ergogen/output/outlines/stack_ol.dxf
ergogen/output/outlines/switch_plate_ol.dxf
hardware/ergogen/output/cases/bottom_plate_cq.stl
hardware/ergogen/output/cases/case_cq.stl
hardware/ergogen/output/cases/switch_plate_cq.stl
hardware/ergogen/output/outlines/board_ol.dxf
hardware/ergogen/output/outlines/bottom_plate_ol.dxf
hardware/ergogen/output/outlines/stack_ol.dxf
hardware/ergogen/output/outlines/switch_plate_ol.dxf

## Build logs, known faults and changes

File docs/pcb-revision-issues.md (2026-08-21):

# PCB revision issues

## Battery reporting conflicts with the P21 key input

Status: open

The current firmware has working ZMK battery-reporting plumbing: both halves
instantiate a battery sensor, the central fetches the peripheral level, and the
central exposes both levels over Bluetooth. The voltage measurement itself is
not reliable, however.

The SuperMini's battery divider is connected to nRF52840 `P0.31` / `AIN7`.
That is also Pro Micro `D21` (`P21`), which this PCB uses as a direct key input:

- left half: `middle_home`
- right half: `inner_top`

Both mappings configure the pin as an active-low input with `GPIO_PULL_UP`. The
nRF52840's internal pull-up is much stronger than the assumed 1 MΩ + 1 MΩ
SuperMini divider, so it pulls the ADC input close to 3.3 V. Firmware then
applies the divider's 2:1 scale, obtains an apparent voltage above 4.2 V, and
clamps the reported charge to 100%.

Relevant files:

- `hardware/ergogen/config.yaml`, `pcbs.shield-pcb.footprints.mcu-fp.P21`
- `firmware/config/boards/shields/ergogenesis/ergogenesis.dtsi`
- `firmware/config/boards/shields/ergogenesis/ergogenesis_right.overlay`

### Preferred fix

Move the affected key net from `P21` to an unused SuperMini extra pin such as
`P1.01` or `P1.02`. Enable the extra pads in the Ergogen MCU footprint, route
the key to the new pad, and update both halves' `input-gpios` mappings. Leave
`P0.31` dedicated to battery sensing.

This avoids coupling key scanning to battery measurement and can continue to
use ZMK's standard battery-voltage-divider driver.

### Keeping P21 connected to a key

It is possible to share the pin, but the battery network must also act as the
key's pull-up. Do not enable the nRF52840 internal pull-up.

Design the effective divider so that its midpoint:

1. stays above the GPIO input-high threshold at the lowest usable battery
   voltage; and
2. stays below the ADC input limit at the highest charging voltage.

For a 3.3 V GPIO supply, a 3.45-4.20 V LiPo range, and the SAADC configuration
currently used by ZMK, a midpoint near 75% of battery voltage is a reasonable
starting target. It gives approximately 2.59-3.15 V. Those figures need to be
checked against the nRF52840 electrical specification and real controller
boards before choosing parts.

If the SuperMini really has a 1 MΩ upper and 1 MΩ lower resistor, adding roughly
499 kΩ from switched battery power (`RAW`) to `P0.31` puts that resistor in
parallel with the upper 1 MΩ resistor and moves the ratio close to 75%. This is
only an example calculation. SuperMini clones do not necessarily use the same
resistor values, so measure the fitted board or obtain its schematic first.
The devicetree `output-ohms` and `full-ohms` values must match the resulting
network.

Sharing still needs firmware work:

- configure the P21 key input without `GPIO_PULL_UP`;
- reject or retry a battery sample while the key is held, since pressing it
  grounds the ADC input and otherwise looks like an empty battery;
- preserve the previous battery value when a sample is rejected; and
- verify that suspend/resume does not re-enable an internal pull.

A custom battery sensor driver may be needed for the sample filtering. The
stock voltage-divider driver will accept a grounded sample and report 0%.

An analog switch could instead alternate `P0.31` between the key and battery
divider, but it adds parts, requires another control signal, and still needs
sampling coordination in firmware. Moving the key to an extra MCU pin is
simpler and less fragile.

### Verification for the next revision

- Measure battery voltage and `P0.31` voltage with USB disconnected at full,
  mid, and near-empty charge.
- Check the calculated voltage against a multimeter before trusting the
  percentage.
- Test the P21 key across the full battery range.
- Hold and repeatedly press the P21 key across several 60-second battery sample
  intervals; the reported level must not jump to 0% or 100%.
- Verify both local and peripheral battery values on the central half.
- Repeat while charging over USB and after suspend/resume.

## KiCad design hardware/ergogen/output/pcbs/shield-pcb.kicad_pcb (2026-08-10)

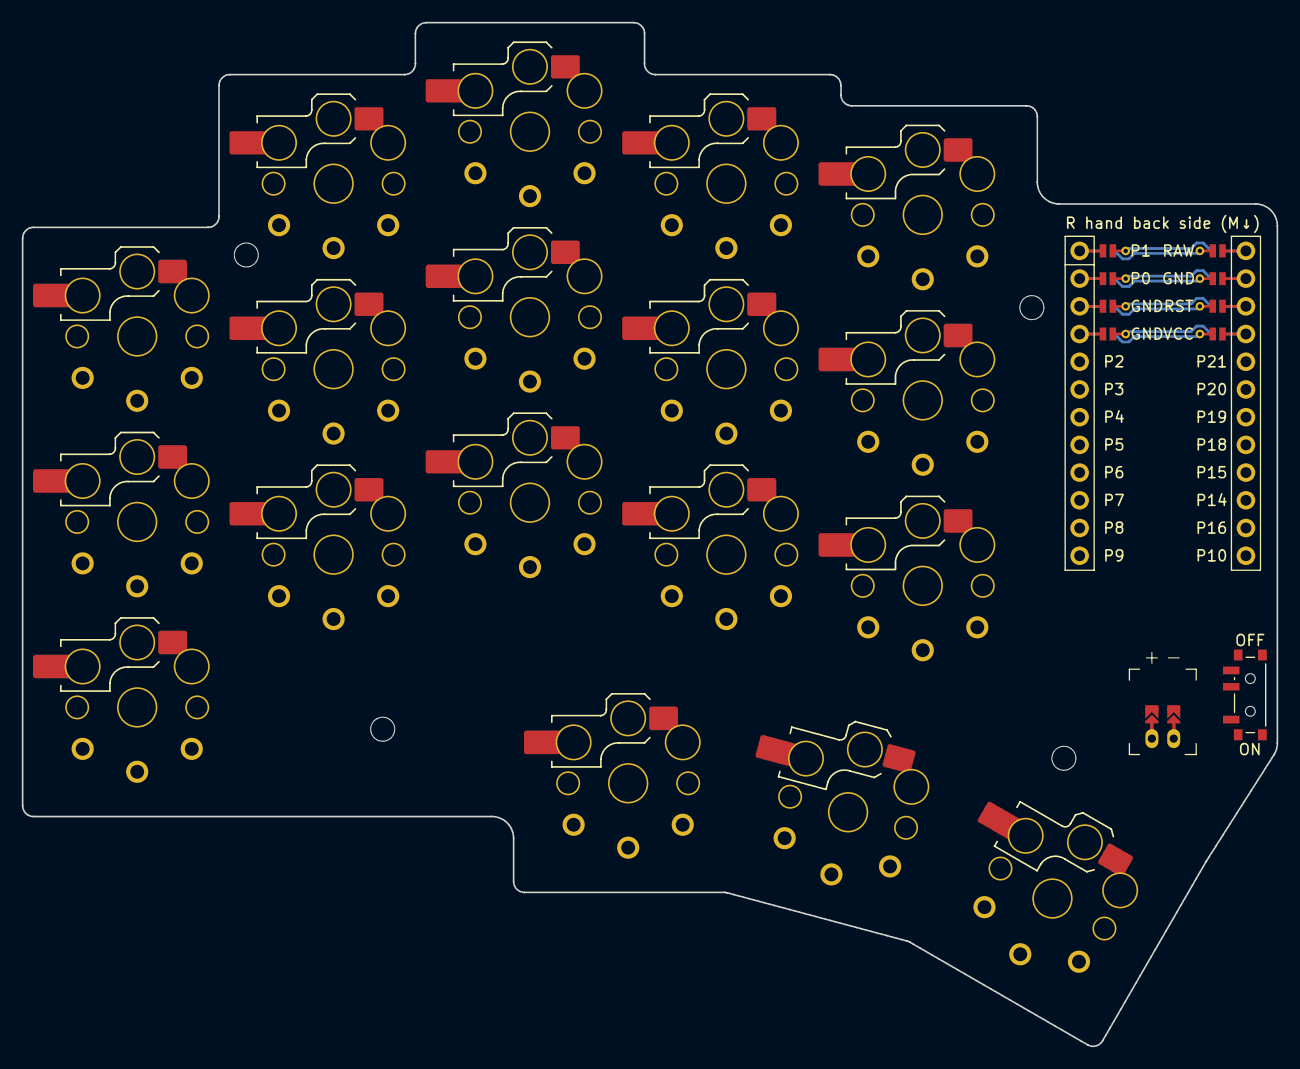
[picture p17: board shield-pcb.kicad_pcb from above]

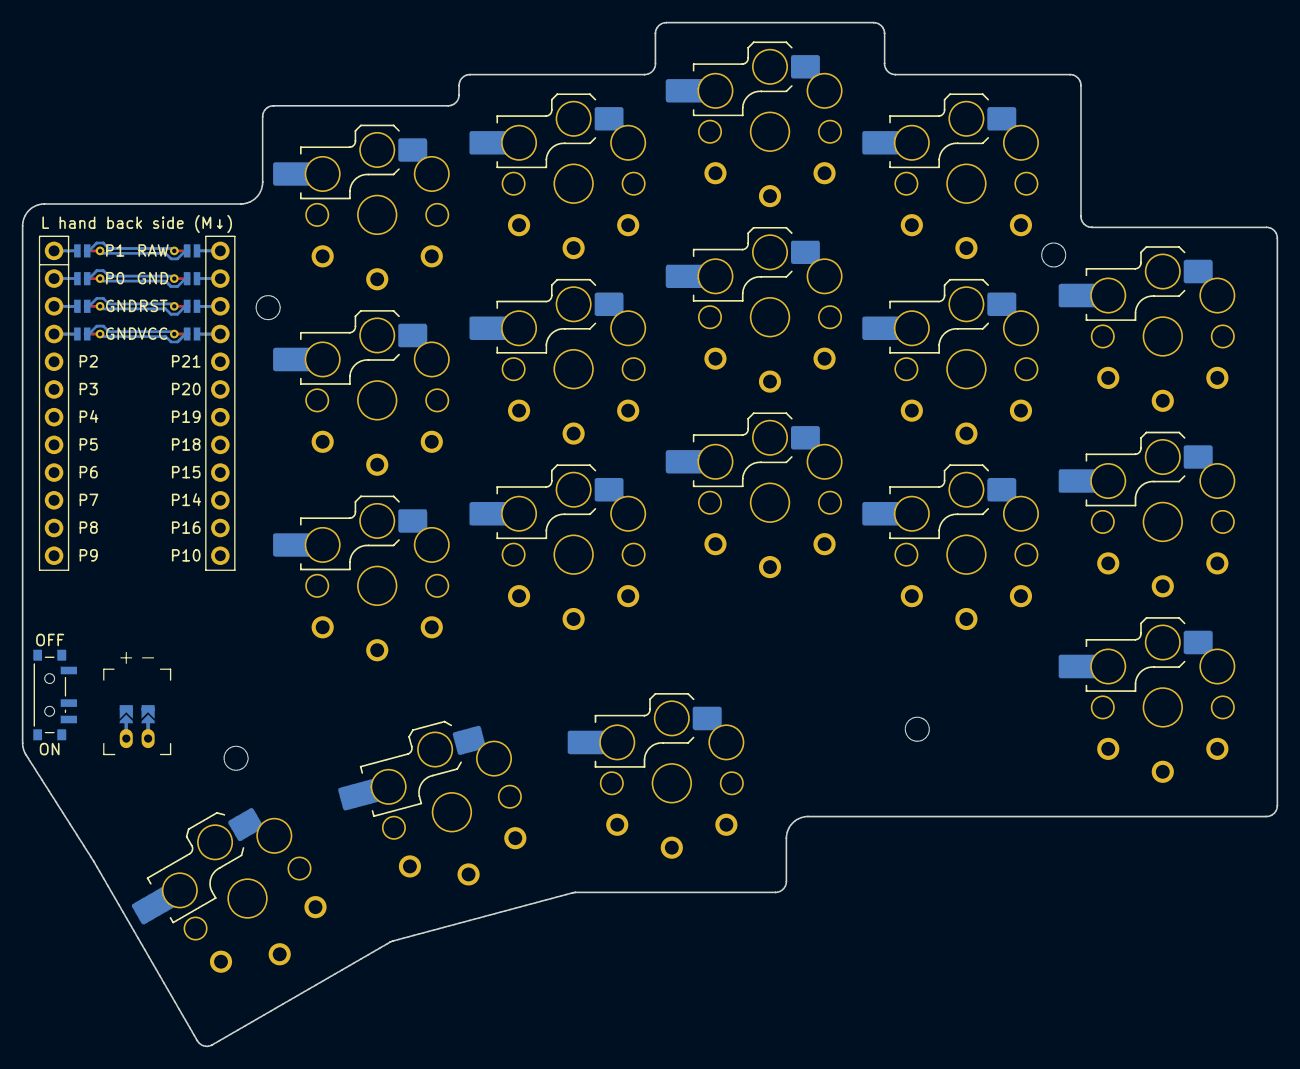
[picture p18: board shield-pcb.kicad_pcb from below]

Board: 2 copper layers, 115.0 x 93.8 mm, 25 parts (18 on the bottom side), 23 nets.

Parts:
JST1: battery_connector_jst_ph_2
MCU1: mcu_supermini_nrf52840
MH1, MH2, MH3, MH4: mounting_hole_npth
PWR1: power_switch_smd_side
S1, S2, S3, S4, S5, S6, S7, S8, S9, S10, S11, S12, S13, S14, S15, S16, S17, S18: switch_choc_v1_v2

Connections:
BAT_P: JST1.1, PWR1.1, PWR1.3
GND: JST1.2, MCU1.102, MCU1.121, MCU1.122, S1.1, S1.2, S2.1, S2.2, S3.1, S3.2, S4.1, S4.2, S5.1, S5.2, S6.1, S6.2, S7.1, S7.2, S8.1, S8.2, S9.1, S9.2, S10.1, S10.2, S11.1, S11.2, S12.1, S12.2, S13.1, S13.2, S14.1, S14.2, S15.1, S15.2, S16.1, S16.2, S17.1, S17.2, S18.1, S18.2
JST1_1: JST1.11, JST1.21, JST1.31
JST1_2: JST1.12, JST1.22, JST1.32
RAW: MCU1.101, PWR1.2
grid-zn_index_bottom: MCU1.14, S10.1, S10.2
grid-zn_index_home: MCU1.19, S11.1, S11.2
grid-zn_index_top: MCU1.6, S12.1, S12.2
grid-zn_inner_bottom: MCU1.13, S13.1, S13.2
grid-zn_inner_home: MCU1.18, S14.1, S14.2
grid-zn_inner_top: MCU1.5, S15.1, S15.2
grid-zn_middle_bottom: MCU1.15, S7.1, S7.2
grid-zn_middle_home: MCU1.20, S8.1, S8.2
grid-zn_middle_top: MCU1.124, S9.1, S9.2
grid-zn_pinky_bottom: MCU1.9, S1.1, S1.2
grid-zn_pinky_home: MCU1.8, S2.1, S2.2
grid-zn_pinky_top: MCU1.7, S3.1, S3.2
grid-zn_ring_bottom: MCU1.16, S4.1, S4.2
grid-zn_ring_home: MCU1.17, S5.1, S5.2
grid-zn_ring_top: MCU1.123, S6.1, S6.2
thumb-zn_far_thumb: MCU1.12, S18.1, S18.2
thumb-zn_home_thumb: MCU1.11, S17.1, S17.2
thumb-zn_near_thumb: MCU1.10, S16.1, S16.2

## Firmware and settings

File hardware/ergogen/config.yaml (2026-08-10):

# yaml-language-server: $schema=https://raw.githubusercontent.com/ergogen/ergogen/refs/heads/master/meta/schema.json

meta:
  engine: 4.1.0 # Min Ergogen version for KiCad 8 footprints
  name: ergogenesis
  version: 1.2
  author: imochoa
  url: https://github.com/imochoa
units:
  # cx: 18mm Choc X spacing
  kx: cx
  # cy: 17mm Choc Y spacing
  ky: cy
  # Padding Variables
  pd: 2
  px: kx + 3
  py: ky + 3
  # U: 19.05mm MX spacing
  # u: 19mm MX spacing
  # For the web preview on ergogen.ceoloide
  $default_width: 18
  $default_height: 17
  # Min sizes of MCU
  mcu_x: 18
  mcu_y: 34
  # Defaults to M2 Screws
  screwSize: 1.5
  standoffSize: 2.5
  # Reset switch sizes
  reset_x: 4.5
  reset_y: 9
  # --- Case / plate variables ---
  # Choc v1 switch-plate cutout (the clip needs ~1.2-1.6mm plate to engage).
  kcow: 13.8 # key cutout width  (choc v1: 13.8, choc v2 / MX: 14)
  kcoh: 13.8 # key cutout height (choc v1: 13.8, choc v2 / MX: 14)
  plate_thickness: 1.6       # stabilization (switch) plate
  bottom_plate_thickness: 2.0 # base plate
  # --- Case variables ---
  wall_height: 5.0           # perimeter wall height above the standoffs (mm)
  wall_thickness: 2.0        # perimeter wall thickness (mm)
  standoff_height: 2.0       # standoff height above the base (mm)
  pcb_to_plate_tolerance: 0.25
  # Hotswap-socket clearance cutout in the base. The Choc hotswap socket
  # bridges the central hole (0, +5.95) and a side hole at (+/-5, +3.75) in
  # the key's local frame (+Y = north / toward the top row). On a reversible
  # board the socket sits bottom-WEST when populated on the front and
  # bottom-EAST when populated on the back. One symmetric slot covers BOTH
  # positions, so a single base works for either side (and for both halves
  # of a split where one PCB is flipped).
  # from AI
  # socket_cutout_w: 12
  # socket_cutout_h: 5
  # my measurements in FreeCAD
  socket_cutout_w: 19
  socket_cutout_h: 8
  socket_cutout_y: 4.85 # north side of the key, mm
  # USB-C port cutout width (the connector is ~9mm; add clearance for the plug).
  usb_cutout_w: 11
points:
  zones:
    grid-zn:
      anchor:
        # Fix placement on KiCAD sheet.
        shift: [150, -150]
        # rotate: +8
      key:
        padding: 1ky
        spread: 1kx
      columns:
        pinky:
          key:
            rotate: 0
            # col_net: P7
          rows:
            bottom:
              # shift: [-1, 0]
            home:
              rotate: 0
            #   shift: [-2, 0]
            top:
              rotate: 0
            #   shift: [-2, 0]
        ring:
          key:
            splay: 0
            # origin: [-12, -19]
            # stagger: 12.573
            # stagger: 0.66U
            # TODO: is this stagger enough???
            # stagger: 0.4U
            # too much stagger?
            stagger: 14
            # shift: [0,0]
          rows:
            bottom:
              # splay: -50
              # shift: [-1, 0]
              rotate: 0
            home:
              rotate: 0
            #   shift: [-1, 0]
            top:
              rotate: 0
            #   shift: [-1, 0]
        middle:
          key:
            splay: 0
            # stagger: +4.763
            stagger: +0.25U
          rows:
            bottom:
              shift: [0, 0]
            home:
              rotate: 0
            top:
              rotate: 0
        index:
          key:
            # splay:
            # stagger: -4.763
            stagger: -0.25U
            # shift: [0,0]
            # anchor:
            #   shift: [5, 0]
          rows:
            bottom:
              # splay: -50
              shift: [0, 0]
            home:
              shift: [+0, 0]
            top:
              shift: [+0, 0]
        inner:
          key:
            rotate: 0
            # stagger: -4
            stagger: -0.15U
          rows:
            bottom:
              rotate: 0
              # splay: -50
            home:
              shift: [+0, 0]
            top:
              shift: [+0, 0]
      rows:
        bottom:
          rotate: 0
        home:
          rotate: 0
        top:
          rotate: 0
    thumb-zn:
      key:
        padding: 1ky
        spread: 1kx
      anchor:
        ref: grid-zn_index_bottom
        # shift: [12.573, -23.81]
        # shift: [0, -py]
        # shift: [0.66U, -1.25U]
        shift: [-0.5kx, -1.1U]
        # rotate: -10
      columns:
        near:
          key:
            rotate: 0
        home:
          key:
            # rotate: 0
            spread: U
            splay: -15
            origin: [-0.5U+0, -0.5U+4]
            # shift: [0, -2.86]
        far:
          key:
            # spread: 19
            # splay: -5
            # origin: [ -45, -15]
            # shift: [0, -10]
            splay: -15
            origin: [-0.5U, -0.5U]
      rows:
        thumb:
          rotate: 0
    mcu-zn:
      anchor:
        ref.aggregate.parts: [grid-zn_inner_top]
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

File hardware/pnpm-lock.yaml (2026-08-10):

lockfileVersion: '9.0'

settings:
  autoInstallPeers: true
  excludeLinksFromLockfile: false

importers:

  .:
    dependencies:
      ergogen:
        specifier: ^4.1.0
        version: 4.1.0
      fs:
        specifier: 0.0.1-security
        version: 0.0.1-security
    devDependencies:
      nodemon:
        specifier: ^3.0.0
        version: 3.1.14

packages:

  '@babel/runtime@7.21.0':
    resolution: {integrity: sha512-xwII0//EObnq89Ji5AKYQaRYiW/nZ3llSv29d49IuxPhKbtJoLP+9QUUZ4nVragQVtaVGeZrpB+ZtG/Pdy/POw==}
    engines: {node: '>=6.9.0'}

  '@danmarshall/jscad-typings@1.0.0':
    resolution: {integrity: sha512-MGGIGDItK2UQSsz7yTrXErQXDAFXR3UPxyQ7WZ5RHOwnv60CBXjmkJlXYMYPkSvo+7fUuQL2/ODcvECtc/fi9g==}

  '@ijprest/kle-serial@https://codeload.github.com/ergogen/kle-serial/tar.gz/61f29f317d87bbfed0b0b7e646e1b91d4384ac02':
    resolution: {tarball: https://codeload.github.com/ergogen/kle-serial/tar.gz/61f29f317d87bbfed0b0b7e646e1b91d4384ac02}
    version: 0.15.1

  '@types/bezier-js@0.0.6':
    resolution: {integrity: sha512-kXsAlt8e8N6zt9R6LcMYWB1HkBw3q2g+M9BdI/UE+s4agIONuIscQaRCoInH22+Jas3rw8yLUehL2InaZjyNSA==}

  '@types/node@7.10.14':
    resolution: {integrity: sha512-29GS75BE8asnTno3yB6ubOJOO0FboExEqNJy4bpz0GSmW/8wPTNL4h9h63c6s1uTrOopCmJYe/4yJLh5r92ZUA==}

  '@types/opentype.js@0.7.2':
    resolution: {integrity: sha512-Riz6WyBUBEFs7YqSsJya3SbDHJZ6BmMkY7bzNoue6rtwj+RNilLc+mgOX/eJ0Y0asq16FSU6DatBeOg8ZMy2UQ==}

  '@types/pdfkit@0.7.36':
    resolution: {integrity: sha512-9eRA6MuW+n78yU3HhoIrDxjyAX2++B5MpLDYqHOnaRTquCw+5sYXT+QN8E1eSaxvNUwlRfU3tOm4UzTeGWmBqg==}

  abbrev@1.1.1:
    resolution: {integrity: sha512-nne9/IiQ/hzIhY6pdDnbBtz7DjPTKrY00P/zvPSm5pOFkl6xuGrGnXn/VtTNNfNtAfZ9/1RtehkszU9qcTii0Q==}

  ansi-regex@5.0.1:
    resolution: {integrity: sha512-quJQXlTSUGL2LH9SUXo8VwsY4soanhgo6LNSm84E1LBcE8s3O0wpdiRzyR9z/ZZJMlMWv37qOOb9pdJlMUEKFQ==}
    engines: {node: '>=8'}

  ansi-styles@4.3.0:
    resolution: {integrity: sha512-zbB9rCJAT1rbjiVDb2hqKFHNYLxgtk8NURxZ3IZwD3F6NtxbXZQCnnSi1Lkx+IDohdPlFp222wVALIheZJQSEg==}
    engines: {node: '>=8'}

  anymatch@3.1.3:
    resolution: {integrity: sha512-KMReFUr0B4t+D+OBkjR3KYqvocp2XaSzO55UcB6mgQMd3KbcE+mWTyvVV7D/zsdEbNnV6acZUutkiHQXvTr1Rw==}
    engines: {node: '>= 8'}

  argparse@1.0.10:
    resolution: {integrity: sha512-o5Roy6tNG4SL/FOkCAN6RzjiakZS25RLYFrcMttJqbdd8BWrnA+fGz57iN5Pb06pvBGvl5gQ0B48dJlslXvoTg==}

  balanced-match@4.0.3:
    resolution: {integrity: sha512-1pHv8LX9CpKut1Zp4EXey7Z8OfH11ONNH6Dhi2WDUt31VVZFXZzKwXcysBgqSumFCmR+0dqjMK5v5JiFHzi0+g==}
    engines: {node: 20 || >=22}

  bezier-js@2.6.1:
    resolution: {integrity: sha512-jelZM33eNzcZ9snJ/5HqJLw3IzXvA8RFcBjkdOB8SDYyOvW8Y2tTosojAiBTnD1MhbHoWUYNbxUXxBl61TxbRg==}

  binary-extensions@2.2.0:
    resolution: {integrity: sha512-jDctJ/IVQbZoJykoeHbhXpOlNBqGNcwXJKJog42E5HDPUwQTSdjCHdihjj0DlnheQ7blbT6dHOafNAiS8ooQKA==}
    engines: {node: '>=8'}

  brace-expansion@5.0.2:
    resolution: {integrity: sha512-Pdk8c9poy+YhOgVWw1JNN22/HcivgKWwpxKq04M/jTmHyCZn12WPJebZxdjSa5TmBqISrUSgNYU3eRORljfCCw==}
    engines: {node: 20 || >=22}

  braces@3.0.2:
    resolution: {integrity: sha512-b8um+L1RzM3WDSzvhm6gIz1yfTbBt6YTlcEKAvsmqCZZFw46z626lVj9j1yEPW33H5H+lBQpZMP1k8l+78Ha0A==}
    engines: {node: '>=8'}

  chokidar@3.5.3:
    resolution: {integrity: sha512-Dr3sfKRP6oTcjf2JmUmFJfeVMvXBdegxB0iVQ5eb2V10uFJUCAS8OByZdVAyVb8xXNz3GjjTgj9kLWsZTqE6kw==}
    engines: {node: '>= 8.10.0'}

  cliui@8.0.1:
    resolution: {integrity: sha512-BSeNnyus75C4//NQ9gQt1/csTXyo/8Sb+afLAkzAptFuMsod9HFokGNudZpi/oQV73hnVK+sR+5PVRMd+Dr7YQ==}
    engines: {node: '>=12'}

  clone@1.0.4:
    resolution: {integrity: sha512-JQHZ2QMW6l3aH/j6xCqQThY/9OH4D/9ls34cgkUBiEeocRTU04tHfKPBsUK1PqZCUQM7GiA0IIXJSuXHI64Kbg==}
    engines: {node: '>=0.8'}

  color-convert@2.0.1:
    resolution: {integrity: sha512-RRECPsj7iu/xb5oKYcsFHSppFNnsj/52OVTRKb4zP5onXwVF3zVmmToNcOfGC+CRDpfK/U584fMg38ZHCaElKQ==}
    engines: {node: '>=7.0.0'}

  color-name@1.1.4:
    resolution: {integrity: sha512-dOy+3AuW3a2wNbZHIuMZpTcgjGuLU/uBL/ubcZF9OXbDo8ff4O8yVp5Bf0efS8uEoYo5q4Fx7dY9OgQGXgAsQA==}

  complex.js@2.1.1:
    resolution: {integrity: sha512-8njCHOTtFFLtegk6zQo0kkVX1rngygb/KQI6z1qZxlFI3scluC+LVTCFbrkWjBv4vvLlbQ9t88IPMC6k95VTTg==}

  core-util-is@1.0.3:
    resolution: {integrity: sha512-ZQBvi1DcpJ4GDqanjucZ2Hj3wEO5pZDS89BWbkcrvdxksJorwUDDZamX9ldFkp9aw2lmBDLgkObEA4DWNJ9FYQ==}

  debug@4.4.3:
    resolution: {integrity: sha512-RGwwWnwQvkVfavKVt22FGLw+xYSdzARwm0ru6DhTVA3umU5hZc28V3kO4stgYryrTlLpuvgI9GiijltAjNbcqA==}
    engines: {node: '>=6.0'}
    peerDependencies:
      supports-color: '*'
    peerDependenciesMeta:
      supports-color:
        optional: true

  decimal.js@10.4.3:
    resolution: {integrity: sha512-VBBaLc1MgL5XpzgIP7ny5Z6Nx3UrRkIViUkPUdtl9aya5amy3De1gsUUSB1g3+3sExYNjCAsAznmukyxCb1GRA==}

  emoji-regex@8.0.0:
    resolution: {integrity: sha512-MSjYzcWNOA0ewAHpz0MxpYFvwg6yjy1NG3xteoqz644VCo/RPgnr1/GGt+ic3iJTzQ8Eu3TdM14SawnVUmGE6A==}
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

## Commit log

2025-08-26 added generation code
    [board.dxf, combo.dxf, keys.dxf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]
2025-09-14 added custom footprints
2025-09-14 finished the pcb generation
2025-10-19 added 3D models
    [bottom_cs.stl, case_cs.stl, clamp-ol.dxf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]
2025-11-16 fixed the custom board structure
2026-02-08 added ergogen-footprints submodule
2026-02-08 cleaned up reversible board
2026-02-09 swapped the pcb footprints
    [config.yaml]
2026-02-10 moved my footprints
2026-06-27 fixed weird space between columns
    [config.yaml]
2026-07-12 Add AISLER DRC rules, kicad-drc-aisler recipe, and shift MCU for routing
    - Download AISLER manufacturer DRC rules (2L-simple, 2L-hd, 4L-hd) from
    AislerHQ/aisler-support to ergogen/drc/
    - Add 'just kicad-drc-aisler' recipe that temporarily patches .kicad_pro
    with AISLER clearance/track/via rules, copies the .kicad_dru, runs DRC,
    and restores the originals. Defaults to aisler-2L-hd profile.
    - Shift MCU 2mm right (+22 X) and 4mm up (-16 Y) to open routing gaps:
    inner-column-to-MCU pins: 2.4mm → 4.4mm
    MCU-bottom-to-thumb-cluster: 13.1mm → 17.1mm
    - Widen eastfill outline 2mm to keep right-edge margin consistent
    [config.yaml]
2026-07-18 updated footprints
2026-07-18 added order
    [shield-pcb-B_Cu.gbr, shield-pcb-B_Mask.gbr, shield-pcb-B_Paste.gbr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]
2026-07-18 added current cases outlines and pcbs
    [board_ol.dxf, bottom_cs.stl, bottom_plate.stl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]
2026-07-18 added kicad
    [shield-pcb-rounded.kicad_pcb]
2026-07-25 build: port working macOS podman devcontainer pattern from ferris-sweep
    Adapt the proven ferris-sweep-zmk-nix2 build setup so 'just
    generic-build' / 'just build-all' produce .uf2 files for ergogenesis
    inside a podman devcontainer on macOS.
    - .devcontainer/Dockerfile: use build args (BASE_IMAGE, ZEPHYR_VERSION)
    and download just 1.46.0 explicitly (matches the working setup).
    - .devcontainer/scripts/docker-build.sh: new, installs just into the image.
    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
2026-07-25 hw: wip ergogen/kicad pcb updates + build scripts
    - ergogen config + generated outputs (outlines, cases, pcb) regenerated.
    - manual pcb work: shield-pcb routing session, dsn, round-tracks config.
    - build.sh / rebuild.sh / bak.script.sh: local build helper scripts.
    - ergogen/old-config.yaml: reference from previous iteration.
    - pics/: sticker/art assets.
    - flake.lock: nix lock bump.
    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
    [bottom_plate.stl, bottom_plate_ol.dxf, shield-pcb.dsn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]
2026-07-25 moved all hw stuff to hw
    poo
    [board_ol.dxf, bottom_plate_ol.dxf, choc_hotswap.step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]
2026-07-25 updated the pin mappings
    fixed pin mappings
2026-07-27 updated cutout for usb
    [bottom_plate.stl, bottom_plate_ol.dxf, case.stl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]
2026-07-28 Make config/ergogenesis.keymap a working keymap override
    Editing the keymap at config/ergogenesis.keymap (instead of the shield
    dir) broke the build in two ways:
    - The override's relative includes (#include "./36.h" / "./helper.h")
    resolved against config/ rather than the shield dir, so the headers
    were not found. Point them at boards/shields/ergogenesis/ instead.
    - The build then hit a Kconfig abort: ZMK Studio requires nanopb, which
    lives in Zephyr's `optional` group that config/west.yml drops via
    group-filter: [-optional]. Re-add just nanopb explicitly (no optional
    group) so the heavy modules stay excluded but Studio builds.
    Verified: `just build-all` builds all three .uf2 tar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
2026-07-29 Fix &bootloader combo, combo rendering, and move draw to uvx
    Firmware:
    - Enable ZMK's retention boot-mode so `&bootloader` actually enters the
    Adafruit UF2 bootloader on Zephyr 4.1. The 3.5->4.1 bump removed
    NRF_STORE_REBOOT_TYPE_GPREGRET (the mechanism ZMK still defaults to), so
    `&bootloader` silently warm-rebooted back into the app. Wire up the modern
    path: include common/nordic/nrf52840_uf2_boot_mode.dtsi (gpregret retention
    area + zmk,bootmode-to-magic-mapper) and enable RETAINED_MEM / RETENTION /
    RETENTION_BOOT_MODE. Magic value auto-defaults to 0x57 (Adafruit nRF52).
    - Bump bootloader_L/R combo timeout 50ms -> 200ms; a 3-key chord (T+G+B /
    Y+H+N) was too tight to hit with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
    [config.yaml]
2026-08-02 trying to measure battery level
2026-08-07 Update docker.io/zmkfirmware/zmk-dev-arm Docker tag to v4.4
2026-08-07 Pin pnpm for Renovate lockfile updates
2026-08-10 new 3d chain
    [bottom_plate_cq.step, bottom_plate_cq.stl, case_base_ol.dxf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]
2026-08-21 added battery reporting issues
2026-08-24 fixed battery conflicts
2026-09-02 added button for talon dictation
2026-10-12 fix(firmware): disable broken battery reporting
    Override the reporting implied by BLE while the SuperMini battery sensor conflicts with the P21 key input. Keep the intended settings documented for reactivation after the hardware issue is resolved.

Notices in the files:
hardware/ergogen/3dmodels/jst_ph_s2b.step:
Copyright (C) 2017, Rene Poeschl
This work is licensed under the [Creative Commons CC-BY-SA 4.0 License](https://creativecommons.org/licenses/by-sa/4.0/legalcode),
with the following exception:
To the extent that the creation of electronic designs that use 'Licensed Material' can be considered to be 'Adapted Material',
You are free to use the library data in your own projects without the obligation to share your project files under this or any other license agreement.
